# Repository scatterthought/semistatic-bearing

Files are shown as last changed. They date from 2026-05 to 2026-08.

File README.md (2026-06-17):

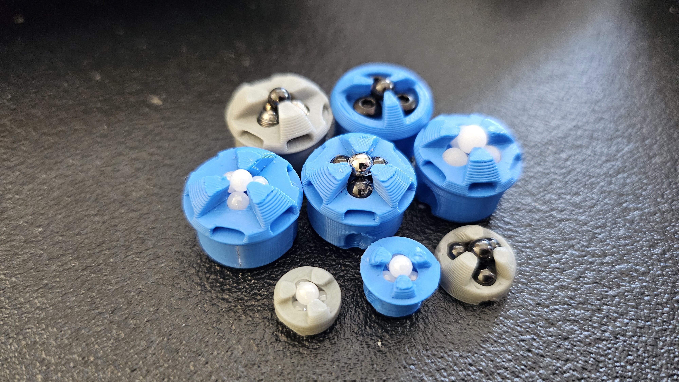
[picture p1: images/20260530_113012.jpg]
Semistatic bearings


# The semistatic bearing
This semistatic bearing is intended for use in trackball pointing devices such as those sold by [Ploopy](https://ploopy.co) and [efog.tech](https://efog.tech). It features a free-spinning main bearing that sits on three embedded subbearings, merging the concepts from static bearings and ball transfer units (BTUs).

Learn more about static bearings and BTUs in [the project background](https://github.com/scatterthought/semistatic-bearing/blob/main/background.md).

## Benefits
I'm confident that a semistatic bearing is better than a static bearing or a cheap BTU. It's smooth and quiet, stiction is virtually non-existent, and supplies are easy to get online. It's also easy to clean since the bearings are exposed.

And then there's the cost.

- With a 50-pack of G10 ceramic bearings for $15, you can make 12 semistatic bearings. 
- 12 printed bearing cases requires 10g of filament; at $20/kg, that's another $0.10. 
- Total cost: $15.10 for 12 units ($1.26 each).

The downside is, of course, that semistatic bearings are 3D-printed. So you have to access to a 3D printer and they won't be as durable as injection-moulded plastic or steel casings.

You're also still going to feel resistance similar to a static bearing, because there's still friction from the embedded bearings. You just won't have to fight stiction when you first move the ball. The amount of resistance will depend on the types of bearings you use and the weight/surface of the larger trackball (e.g. glossy versus matte finish).

Bosch Rexroth BTUs are still the absolute best choice if you want extremely low friction, are okay with some noise, and don't mind paying for the experience. The semistatic bearing is for everyone else...or as a stopgap while you're waiting for the BTUs you ordered to arrive.

## Available models
Additional models will be added over time, and I'm happy to consider requests (within reason).

| Semistatic bearing | Comments |
| ---- | ---- |
| [BR8](https://github.com/scatterthought/semistatic-bearing/blob/main/bosch-rexroth) | Replaces Bosch Rexroth 8mm BTU (KU-B8-OFK) |
| [VC75](https://github.com/scatterthought/semistatic-bearing/blob/main/veichu) | Replaces Veichu 7.5mm BTU (VCN310) |
| NL8H (in development) | Replaces generic NL-8H POM BTU |
| [FLMT](https://github.com/scatterthought/semistatic-bearing/tree/main/custom-bearings) (untested) | Flushmount bearing to replace static bearings in mass-market trackballs |
| [PRFT](https://github.com/scatterthought/semistatic-bearing/tree/main/custom-bearings) | Minimal models for press-fit and remixing |

## Device compatibility list

I'm curating a [list of compatible devices](https://github.com/scatterthought/semistatic-bearing/blob/main/device-compatibility-list.md). If you have semistatic bearings working in a device or want to test and need assistance, please [open an issue](https://github.com/scatterthought/semistatic-bearing/issues).

## Considerations

### Durability
My design employs a three-pointed claw to hold the main bearing in place, and it's the only thing keeping the ball bearings from spilling out. I've found it to be very secure and there shouldn't ever be much force on it, but there's a small chance that it will break if the bearing is handled roughly. It may also wear down if you frequently remove the balls.

If your trackball lives on your desktop, I wouldn't expect the semistatic bearings to fail. However, you might want to keep some extras handy if you travel with it regularly.

### Printer tolerances
Depending on your printer and filiment, the claws may be too tight or too loose. Every 3D printer is different, and it's impossible to produce models that will work on all of them.

- If a claw is too tight, you can sand the tips to loosen its grip on the ball bearing. Just be very careful to not remove too much material. Even just 0.01mm can make a difference.
- If a claw is too loose, try adding nail polish or glue to the top and tip. Again, you don't want to add too much.

### Maintenance
The bearing can be easily disassembled for cleaning or recovering/reusing parts. If you prefer a more permanent solution, the subbearings can be glued/caulked in place.

[This Reddit comment](https://www.reddit.com/r/Trackballs/comments/1tm2lfc/comment/onq967s/) recommends also filling in the gaps between the subbearings for easier cleaning. Just make sure that adhesive doesn't hamper the main bearing.
 
### Ball sizes
In all of my models, the main ball and subbearings are the same size. It would be possible to use smaller balls for subbearings, but since they don't spin their size is irrelevant. Their purpose is simply to provide low-friction surfaces for the main ball. So, it's more cost-effective to use the same size for all four balls (which can be bought in packs of 25/50/100/200).

## Print settings
All models are designed for 0.2mm layers.

- I recommend ironing (on all surfaces) for bearings with flat tops.
- No other special settings are required.

## Supplies
Any ball bearings should work, but I recommend ceramic balls of at least G10 (preferably G5).
- You'll need four ball bearings for each semistatic bearing.
- My testing has mostly been done with [uxcell 3mm Silicon Nitride G5](https://www.amazon.ca/dp/B0B5XK3BTM) and [uxcell 2.5mm Zirconium Oxide G5](https://www.amazon.ca/dp/B0B5XKBSV6/) ceramic ball bearings.

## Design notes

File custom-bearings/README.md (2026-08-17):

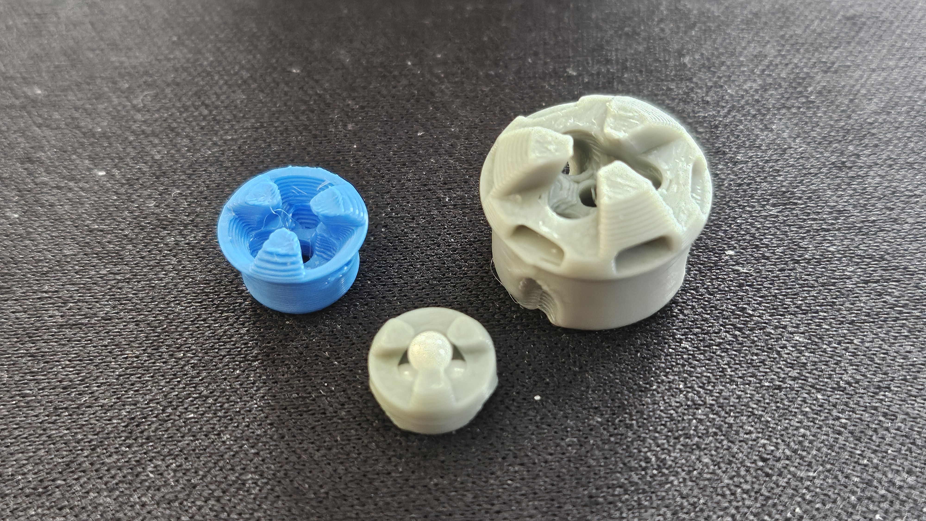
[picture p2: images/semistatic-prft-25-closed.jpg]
Press-fit semistatic bearing with VC75 and BR8 models


# Flushmount bearings
This version is designed to fit in a hole drilled into a trackball's ball cradle with a 12.7mm (1/2") bit. The collar is oval-shaped to counter the cradle's curvature. It's been physically tested with a non-functional Kensington Expert, but is not confirmed to work.

- [12.6mm diameter with 3.0mm ball bearings](https://github.com/scatterthought/semistatic-bearing/edit/main/custom-bearings/semistatic-flmt-30mm-.stl)

# Press-fit bearings
These compact versions are ideal for press-fit applications with limited space.
- [3.0mm ball bearings, 9mm diameter x 5mm height](/custom-bearings/semistatic-flmt-30mm-9x5.stl)
- [2.5mm ball bearings with closed top](/custom-bearings/semistatic-prft-25mm-closed.stl)
- [2.5mm ball bearings with open top ](/custom-bearings/semistatic-prft-25mm-open.stl)

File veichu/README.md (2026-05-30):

# Semistatic bearing replacements for Veichu BTUs

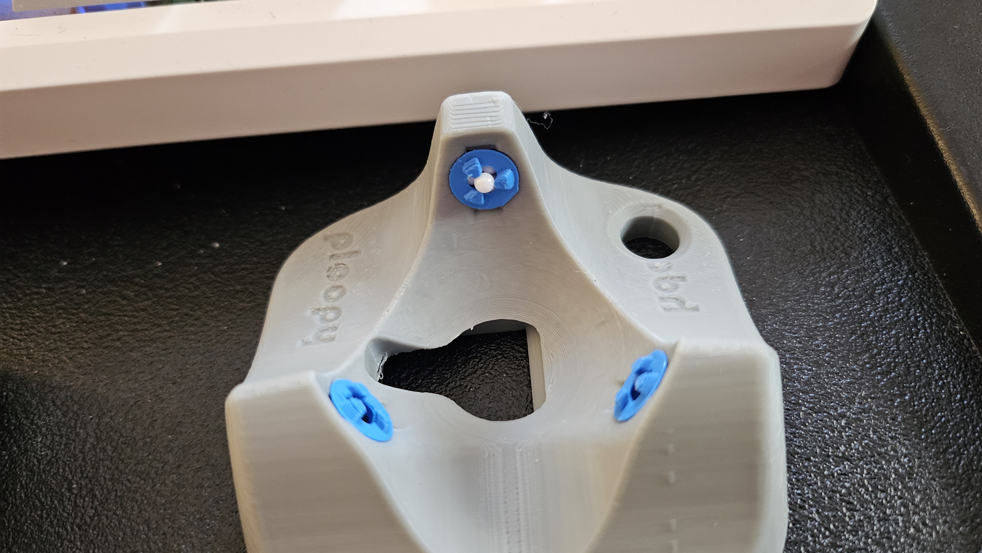
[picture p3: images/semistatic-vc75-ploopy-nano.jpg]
Semistatic bearing in Ploopy Nano


Veichu makes mid-grade BTUs that can vary in quality. They aren't as smooth or quiet as Bosch Rexroth BTUs, but are 1/3rd of the price.

## VCN310 (7.5mm)
[Manufacturer's technical information](https://www.veichu.com/VCN310-Stainless-Steel-Ball-Transfer-Unit-pd585435958.html)

### Models
This model is a replacement for the VCN310 7.5mm bearing, which is popular due to its small size. There are versions with open and closed tops. The subbearings are more secure in the closed-top version, but are harder to remove.

- [Closed top](https://github.com/scatterthought/semistatic-bearing/blob/main/veichu/semistatic-vc75-closed.stl)
- [Open top](https://github.com/scatterthought/semistatic-bearing/blob/main/veichu/semistatic-vc75-open.stl)

### Assembly
1. Insert three 2.5mm balls into the subbearing sockets in the bearing case.
2. Press the balls fully into their sockets with your fingernail or a hex key.
3. Perch a 2.5mm ball on top of the claw.
4. Press the ball down to click it into place.

### Disassembly
- To remove the main bearing, push a small hex key (or something similar) through the 2mm hole in the bottom of the case.
- Point the claw into your hand (or a container) to catch the bearings when they pop out, or you may never see them again!

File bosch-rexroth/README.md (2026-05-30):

# Bosch Rexroth

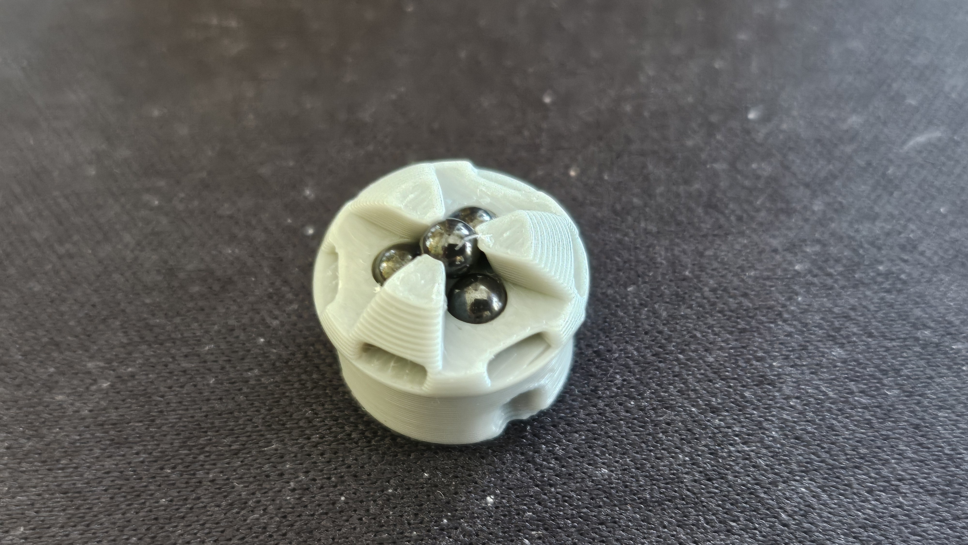
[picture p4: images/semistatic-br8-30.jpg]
Semistatic bearings in an Endgame trackball


Bosch Rexroth ball transfer units (BTUs) are the best of the best. As a result, many trackball mods are designed specifically for them.

## KU-B8-OFK (8mm BTU)
[Manufacturer's technical information](https://store.boschrexroth.com/en/ca/p/ball-transfer-unit-r053010810)

### Models
This model uses 2.5mm, 3mm, or 3.5mm balls for the main bearing and subbearings.There are slots in the tops of the cases that can be gripped with a keyboard-switch puller for easy removal from a trackball.

- [2.5mm ball bearings](https://github.com/scatterthought/semistatic-bearing/blob/main/bosch-rexroth/semistatic-br8-25mm.stl)
- [3.0mm ball bearings](https://github.com/scatterthought/semistatic-bearing/blob/main/bosch-rexroth/semistatic-br8-30mm.stl)
- [3.5mm ball bearings](https://github.com/scatterthought/semistatic-bearing/blob/main/bosch-rexroth/semistatic-br8-35mm.stl)

### Assembly
1. Drop three balls into the three sockets in the bearing case.
2. Perch another ball on top of the claw.
3. Use the bottom of another bearing case to press the ball down and click it into place.

### Disassembly
- To remove the main bearing, push a small hex key (or something similar) through the 2mm hole in the bottom of the case.
- Point the claw into your hand (or a container) to catch the bearings when they pop out, or you may never see them again!

### Spacers
If your bearings don't make proper contact with the trackball, use spacers to raise them in their sockets. The Device Compatibility List provides some tips, but it can be a bit of trial and error. This is particularly the case with trackball mods designed for a range of trackball sizes.

Both spacers are 0.6mm in height, which will print in three layers at 0.2mm. You can change the height in your slicer to adjust your spacing. In some cases, you may only want spacers on one or two of the three bearings in your trackball.

- [Ring](https://github.com/scatterthought/semistatic-bearing/blob/main/bosch-rexroth/semistatic-br8-ring.stl) (12.6mm inner diameter, 15mm outer diameter)
- [Riser](https://github.com/scatterthought/semistatic-bearing/blob/main/bosch-rexroth/semistatic-br8-riser.stl) (12.6mm outer diameter)

## Alternative subbearings
I designed a couple of other Bosch Rexroth 8mm equivalents that use screws as subbearings. I'm publishing them more out of interest than usefulness.

### Grub screws
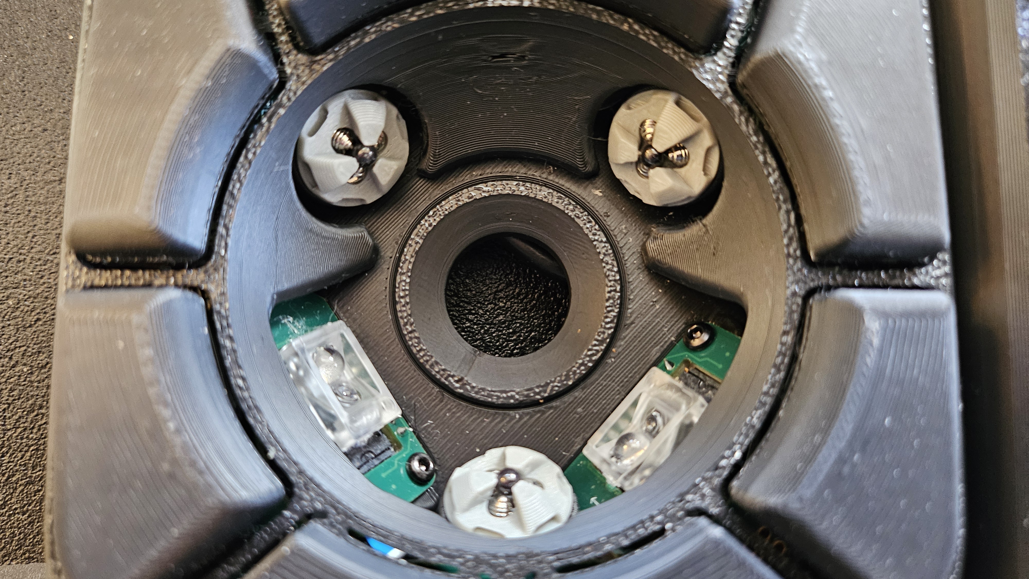
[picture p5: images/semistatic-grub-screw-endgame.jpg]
Semistatic bearing with grub screws in Endgame


I originally designed with ballpoint set screws in mind. Three M4x6mm screws are inserted into the holes pointing upward and adjusted to support the main bearing.
- [Grub-screw semistatic bearing](https://github.com/scatterthought/semistatic-bearing/blob/main/bosch-rexroth/semistatic-br8-grubscrews.stl)

### Button-head screws
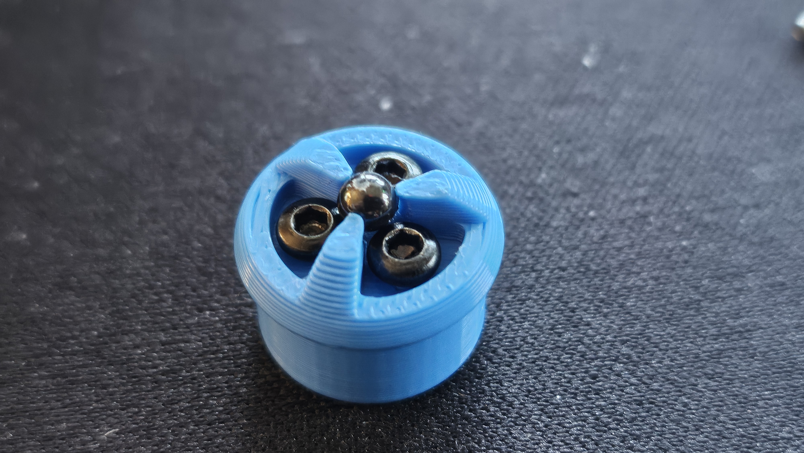
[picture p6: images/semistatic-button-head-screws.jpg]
Semistatic bearing with button-head screws


This model uses the round tops of M2x4 button-head screws as the subbearings. Three M2 button-head screws (4mm or 6mm) are inserted into the bearing case, then raised to support the main bearing.
- [Button-head semistatic bearing](https://github.com/scatterthought/semistatic-bearing/blob/main/bosch-rexroth/semistatic-br8-buttonhead.stl)

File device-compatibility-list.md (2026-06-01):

# Device compatibility list

If you have semistatic bearings working in a device or want to test and need assistance, please [open an issue](https://github.com/scatterthought/semistatic-bearing/issues) or [post a make/comment on Printables](https://www.printables.com/model/1730789-semistatic-bearing/comments).

## Tested successfully

### Trackballs
| Device | Semistatic bearing | Comments |
| ---- | ---- | ---- |
| [efog.tech Endgame](https://efog.tech/products/endgame-trackball-complete-diy-kit) | BR8 | 
| [Ploopy Adept](https://ploopy.co/adept-trackball/) - [Anyball mod](https://github.com/adept-anyball/) | BR8 | Requires 2.4mm spacer ring for OEM 44mm ball;<br>Requires 1.2mm spacer ring for 52mm ball |
| Ploopy Classic 1 - [BTU Mod](https://github.com/ploopyco/classic-trackball/tree/master/hardware/Mechanicals-BTU-Mod) | BR8 | 4mm spacers on two of the three BTU sockets |
| [Ploopy Classic 2](https://ploopy.co/classic-2-trackball/) - [BTU Mod](https://codeberg.org/killmaster/Ploopy-Classic-2-BTU) | BR8 | 8mm spacer on one of the BTU sockets |

### Trackball keyboards
| Device | Semistatic bearing | Comments |
| ---- | ---- | ---- |
| [BastardKB Charybdis Keyboard - Veichu BTU Mod](https://github.com/Bastardkb/Charybdis/blob/main/files/mods/readme.md#btu-mod) | VC75 | [More information on Printables](https://www.printables.com/make/3449131?comment_id=3454264) |

## Testing in progress

### Ploopy Nano 1
- Mod based on [Ploopy Nano with Button](https://www.reddit.com/r/ploopy/comments/1m1xlq1/ploopy_nano_with_button/) using [Semistatic-VC75-open.stl](https://github.com/scatterthought/semistatic-bearing/blob/main/veichu/semistatic-vc75-open.stl) bearing.

### Ploopy Thumb
- A bearing has been developed to match the dimensions of the NL-8H POM BTU used in the Ploopy Thumb Mod.
- To be added to repository when testing has been completed.

## Needs testing

### Kensington Expert
- A flushmount bearing has been developed for the Expert, but has not been tested with a functional device.
- The bearing is designed to fit into a hole drilled with a 12.7mm (1/2") bit.
- It may be possible to use this bearing on a wide range of trackballs.

## Testing wishlist
- [Ploopy BTU mods](https://blog.ploopy.co/mods-index) for the Adept, Mini, and Thumb trackballs
- Consumer trackballs with static bearings (e.g. Elecom, Kensington, Nulea, ProtoArc)
- Trackball keyboards (e.g. keyball, Skeletyl, Svalboard)

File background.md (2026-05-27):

# Project background

## Static bearings
Most trackballs use static bearings: three tiny balls in a triangular pattern, with the main ball perched on them (like a tripod). The bearings are embedded in the shell and don't move at all (hence, "static").

Static bearings are silent and inexpensive, but suffer from [static friction](https://www.britannica.com/science/static-friction) ("stiction"): you have to apply enough force to dislodge the trackball when it's at rest, and when the ball finally moves it jumps too far. Stiction makes it difficult to carry out small, precise movements. It's the bane of all trackballers.

Some static trackballs suffer more than others. You can have two seemingly identical trackballs that have very different stiction, and the only way to guarantee avoiding it is to avoid the static bearings.

## Ball transfer units
A ball transfer unit (BTU) is a specialized type of bearing that contains a big ball bearing sitting on top of a bunch of smaller subbearings that can all move freely within the bearing case. This allows the big bearing to spin freely, since there's very little friction slowing it down. However, BTUs can be noisy due to the ball bearings moving and colliding inside the case. They're generally meant for commercial/industrial use, where noise isn't an issue.

You won't find BTUs in most consumer-focused devices (e.g. Logitech or Kensington), but they're popular in DIY trackballs and modifications. Bosch Rexroth produces the best BTUs, but they're difficult to buy in small quantities and expensive when you can get them (typically CAD$15-20 per unit). That's a significant barrier to entry for a lot of people.

## Put those hands together!
My semistatic design merges the static and BTU concepts. It features a main bearing that can spin freely on subbearings (like a BTU), but the subbearings are embedded and don't spin (like a static bearing). It produces very little noise due to only having one moving part, and virtually eliminates stiction since the trackball doesn't have to fight as much to dislodge itself.  And since it's 3D-printed and filled with inexpensive ball bearings, the only barrier to entry is access to a 3D printer.

## Elecom's BTU announcement
Elecom floated teasers about their [new BTU for the IST and Huge Plus trackballs](https://www.reddit.com/r/Trackballs/comments/1tnus9u/new_ball_transfer_unit_is_launching/) on pretty much the same day I first talked about the [semistatic bearing on Reddit](https://www.reddit.com/r/Trackballs/comments/1tm2lfc/testers_needed_for_a_btu_alternative_the/). They've clearly been working on it for awhile, so the timing is just crazy coincidence.

The concept is very similar, so I would expect it to work well based on my own results. I'm really glad that I got out there first, so that it's clear my work isn't based on theirs.

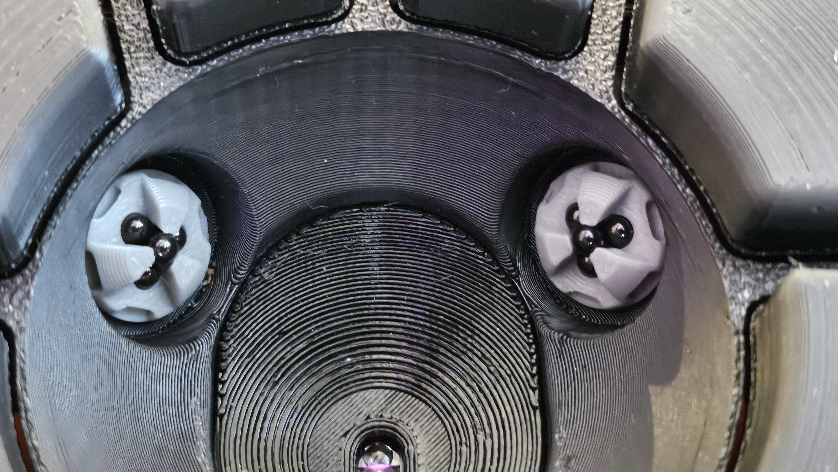
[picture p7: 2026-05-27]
images/semistatic-br8-30-adept-anyball.jpg

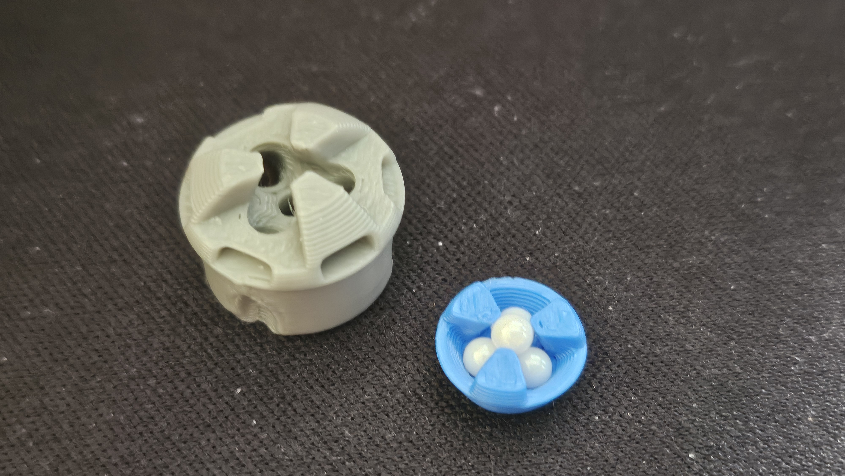
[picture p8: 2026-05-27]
images/semistatic-prft-25-open.jpg

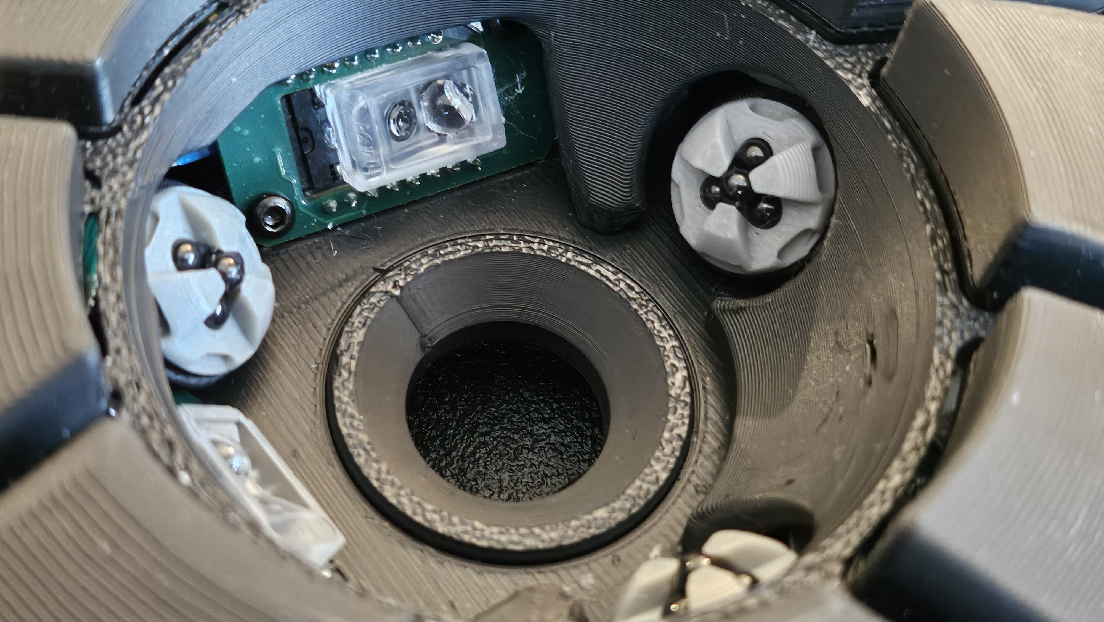
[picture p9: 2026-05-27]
images/semistatic-br8-30-endgame.jpg

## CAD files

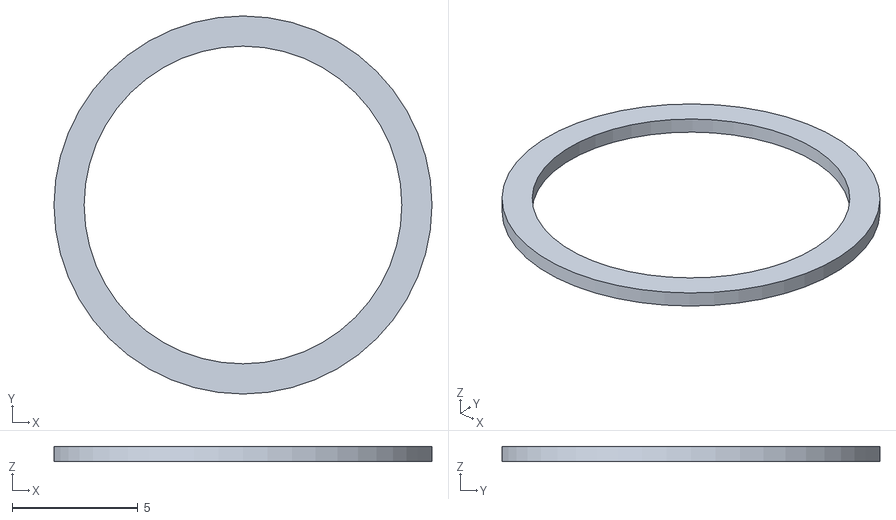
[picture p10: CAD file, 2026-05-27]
bosch-rexroth/semistatic-br8-ring.stl
15.0 x 15.0 x 0.6

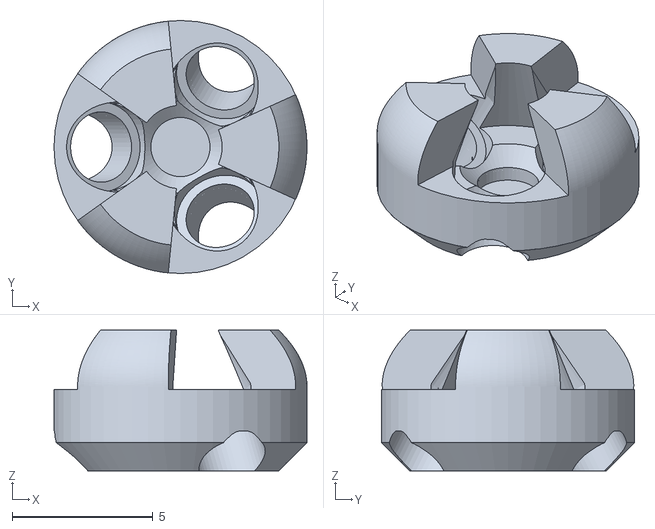
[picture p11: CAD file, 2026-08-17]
custom-bearings/semistatic-flmt-30mm-9x5.stl
9.00 x 9.00 x 5.00

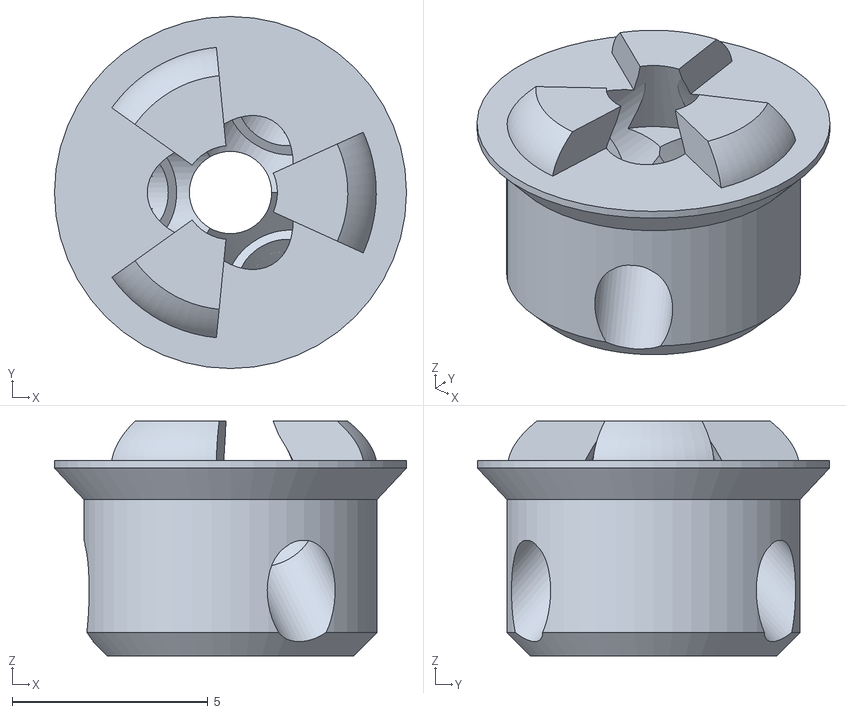
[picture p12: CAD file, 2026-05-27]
veichu/semistatic-vc75-closed.stl
9.00 x 9.00 x 6.00

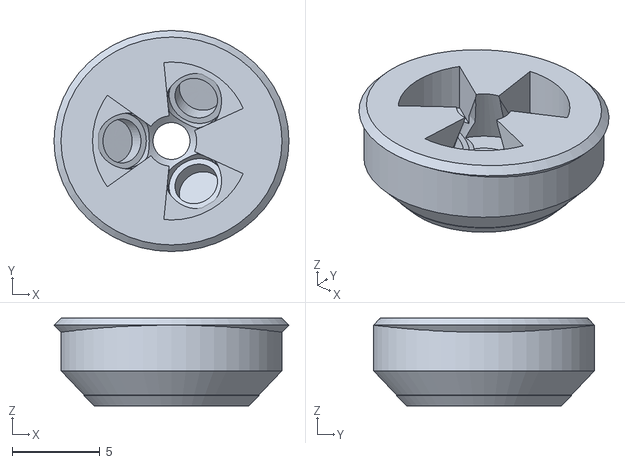
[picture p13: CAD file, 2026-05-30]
custom-bearings/semistatic-flmt-30mm-.stl
13.4 x 12.6 x 5.00

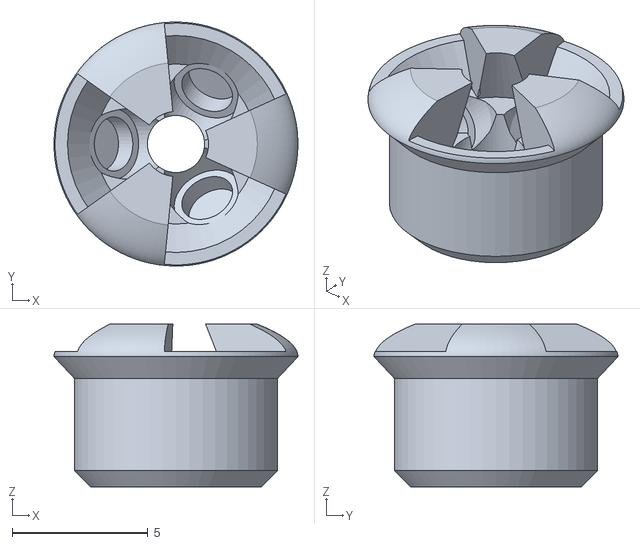
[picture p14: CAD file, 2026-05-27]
veichu/semistatic-vc75-open.stl
9.00 x 9.00 x 6.00

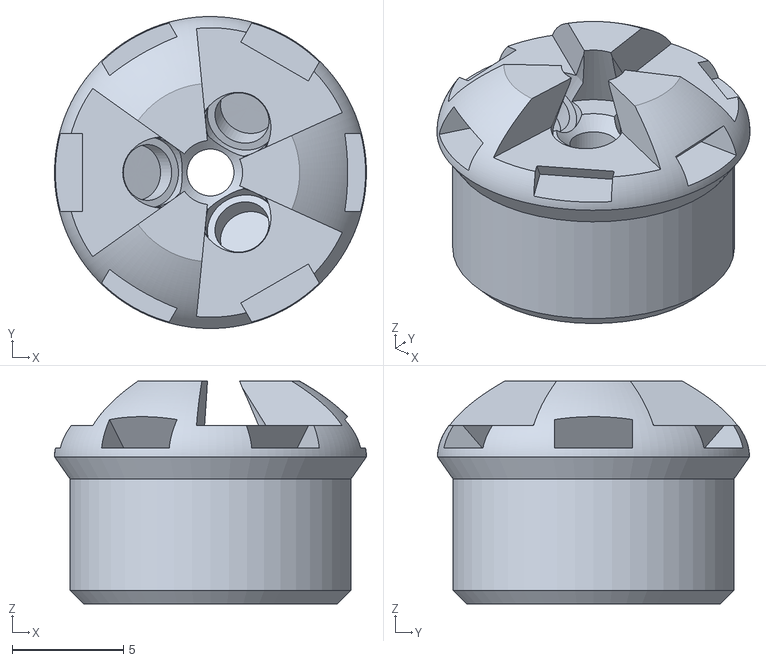
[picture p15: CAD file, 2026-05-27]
bosch-rexroth/semistatic-br8-30mm.stl
14.0 x 14.0 x 10.0

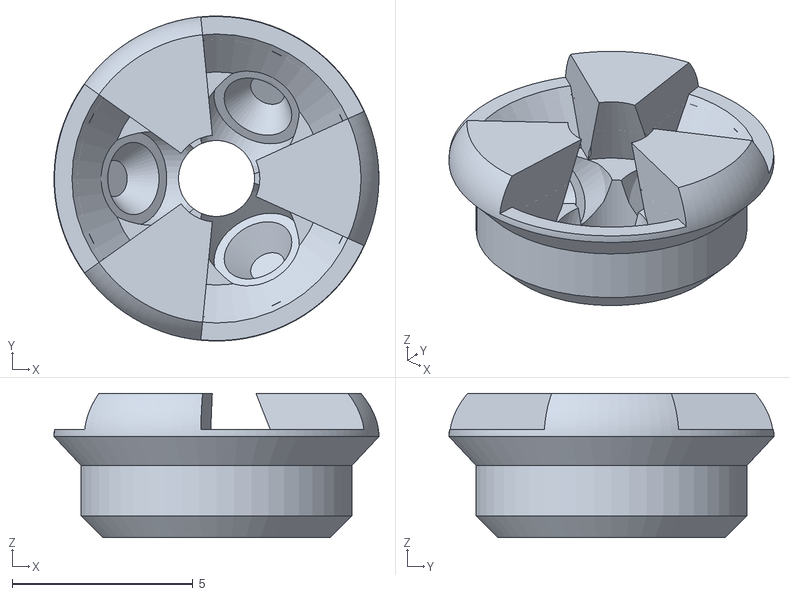
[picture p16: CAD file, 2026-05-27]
custom-bearings/semistatic-prft-25mm-open.stl
9.00 x 9.00 x 4.00

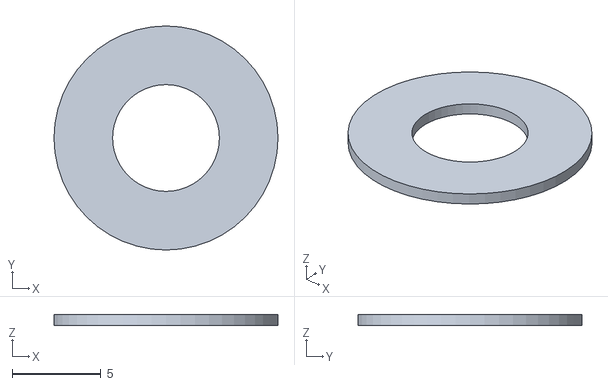
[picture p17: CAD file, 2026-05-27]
bosch-rexroth/semistatic-br8-riser.stl
12.6 x 12.6 x 0.6

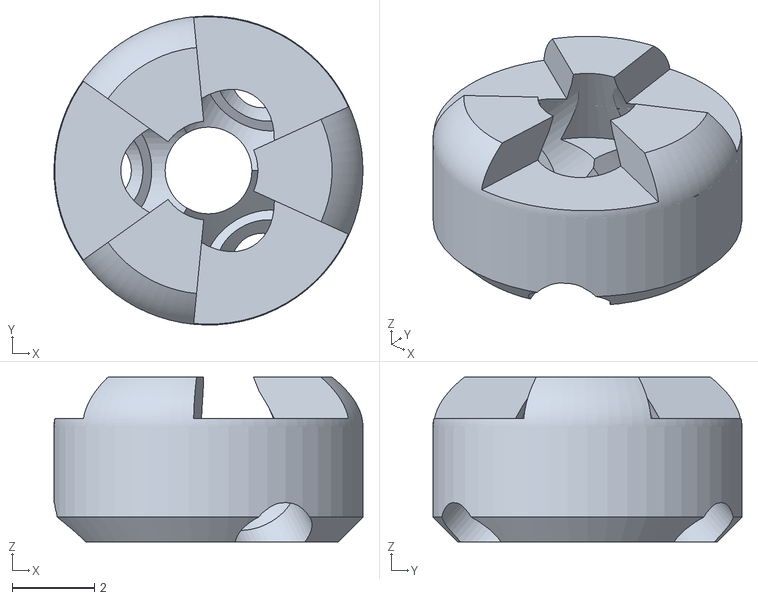
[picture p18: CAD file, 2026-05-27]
custom-bearings/semistatic-prft-25mm-closed.stl
7.50 x 7.50 x 4.00

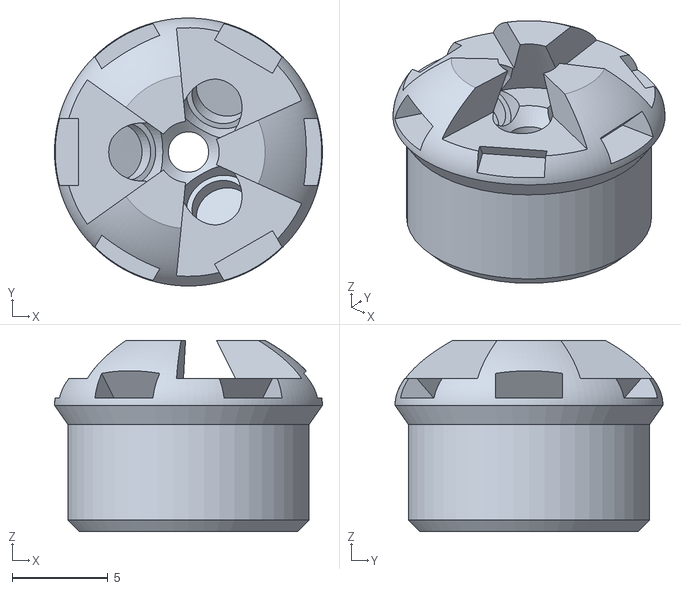
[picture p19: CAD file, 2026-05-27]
bosch-rexroth/semistatic-br8-35mm.stl
14.0 x 14.0 x 10.0

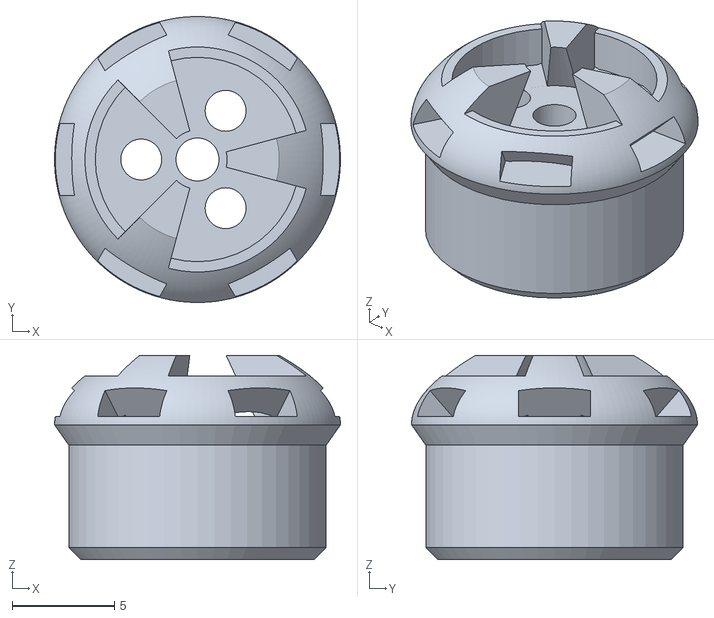
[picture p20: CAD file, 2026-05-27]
bosch-rexroth/semistatic-br8-buttonhead.stl
14.0 x 14.0 x 10.0

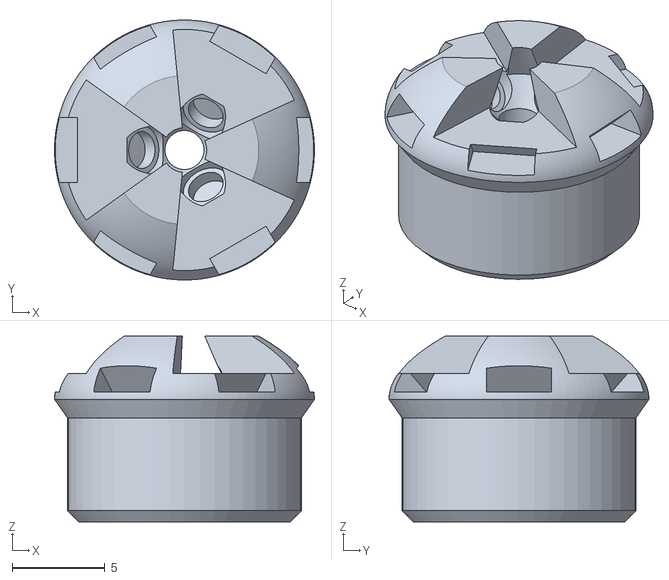
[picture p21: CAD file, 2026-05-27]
bosch-rexroth/semistatic-br8-25mm.stl
14.0 x 14.0 x 10.0

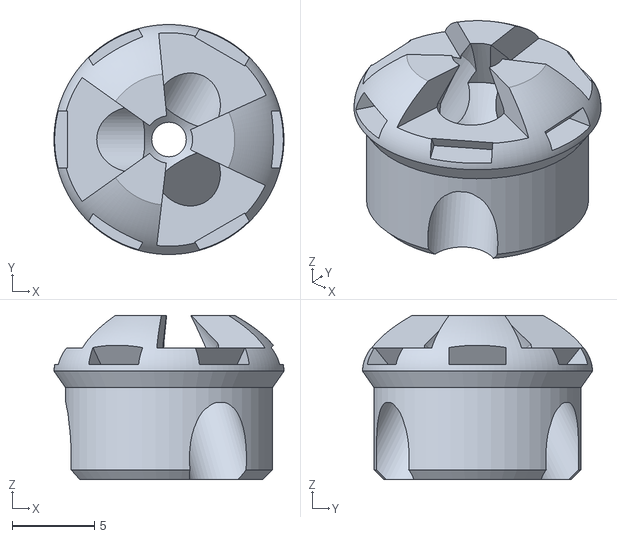
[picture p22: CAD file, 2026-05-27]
bosch-rexroth/semistatic-br8-grubscrews.stl
14.0 x 14.0 x 10.0
